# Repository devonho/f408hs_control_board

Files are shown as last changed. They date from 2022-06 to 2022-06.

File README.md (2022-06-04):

# Control board for Panasonic F-408HS 16" Stand Fan

## *** Warning  ***

This repository contains circuit designs for a printed circuit board that uses 240VAC as a power source, and can hence cause serious injury or death to anyone who implements the design. 

## Disclaimer

By using any of the designs here, you agree to waive the author of all liability for any personal or 3rd party injury or death, or damage to property sustained as a result of using the designs.

## License

These designs were made using a free version of [Autodesk Eagle](http://eagle.autodesk.com). Commercial use of designs is prohibited.

Furthermore: [License](./LICENSE)

## Overview

The design contained here contains both a [schematic](./eagle/F408HS_control.sch) that is inspired by the original board design, and a board [layout](./eagle/F408HS_control.brd) that has been revamped and optimized for 2-layer fabrication and debugging.

## Components and BOM

Most of the components used have been listed in the [Bill-Of-Materials](./eagle/BOM.txt) list. Some special ones that were hard to locate are connectors for the motor (CN1) and the AC input to the control board itself. These are:

* Japan Automatic Machine (JAM) SC25-10WL
* Japan Solderless Terminals (JST) ELR-03V

### Component Values

Values for transistors Q1 and Q2 were determined based on SMD markings, which may be erroneous.

Values for capacitors and zener diode were determined empirically using simulation in [LTSpice](https://www.analog.com/en/design-center/design-tools-and-calculators/ltspice-simulator.html). 

## LT SPICE Simulations

* [Power](./spice/power.asc)
* [Phase Sync](./spice/phase_sync.asc)

## Layout

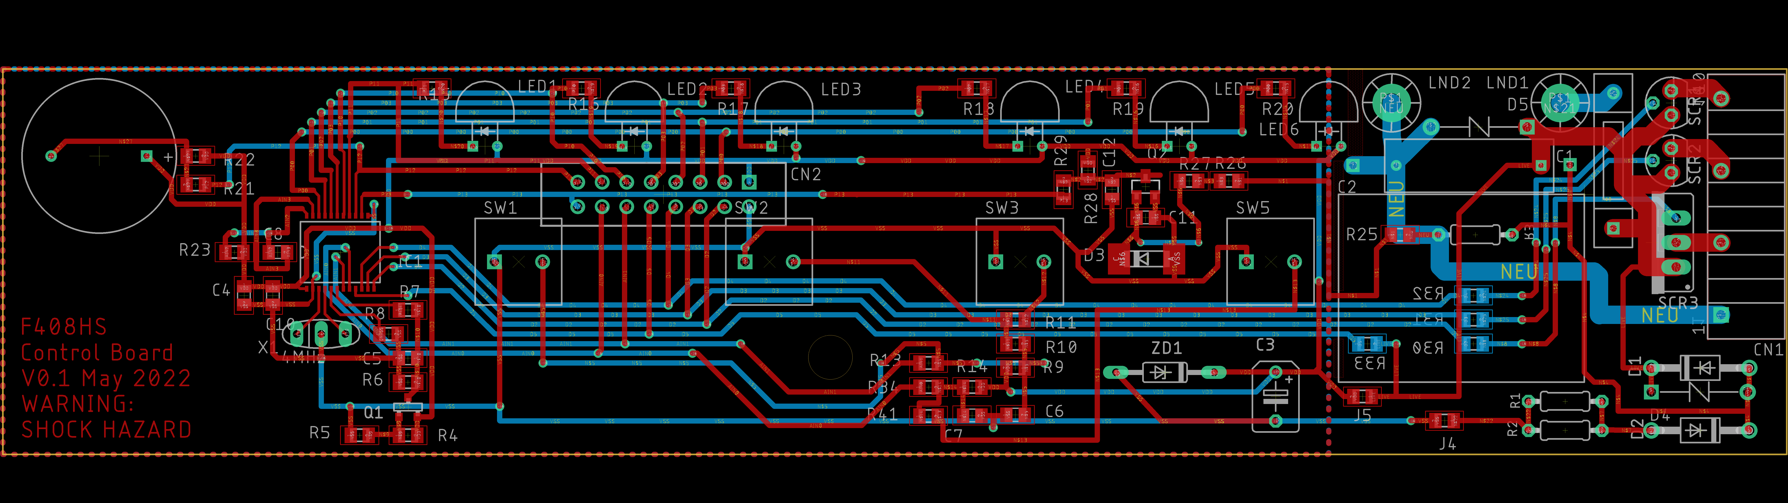
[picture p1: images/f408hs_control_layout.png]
Board layout


The [layout](./eagle/F408HS_control.brd) was designed with 2 layer boards in mind. Without the contraints of a single layer board, J1 - J3 are no longer needed to bridge over tracks.

The 240AC tracks have also been constrained to the right side of the board, making it slightly less risky while probing the board. The AC section can also be left unpopulated, using an externally sourced Vdd and Vss via CN2 for debugging the low voltage section. 

 ## Schematic

 Schematic

 ### AC Phase Sync

 The output of the AC phase sync circuit is connected to P13 of the MCU. Hence it is possible that the interrupt capability of that pin is used to synchronise the TRIAC trigger with the AC phase. Modulating the TRIAC duty cycle is probably needed for the 揺らぎ "Yuragi" fluctuation function, to lower the motor RPM.

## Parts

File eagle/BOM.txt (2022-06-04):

Partlist exported from C:/Users/Devon/OneDrive/projects/f408hs_control_board/eagle/F408HS_control.sch at 4/6/2022 4:26 PM

Part  Value         Device         Package        Description                                                    MF MPN         OC_FARNELL OC_NEWARK POPULARITY SPICEPREFIX
BZ1   BUZZER        BUZZER         BUZZER                                                                                                                                  
C1    0.1uF         ECQU2A104      ECQU2A104                                                                                                                               
C2    0.68uF        ECQUL2A648KL   ECQU2A684      Panasonic ECQUL Polyester Film Capacitor, 275V ac, ±10%, 680nF                                                           
C3    1000uF        CPOL-EUB45181B B45181B        POLARIZED CAPACITOR, European symbol                                                               2          C          
C4    10nF          C-EUC0805      C0805          CAPACITOR, European symbol                                                                         88         C          
C5    10nF          C-EUC0805      C0805          CAPACITOR, European symbol                                                                         88         C          
C6    10nF          C-EUC0805      C0805          CAPACITOR, European symbol                                                                         88         C          
C7    10nF          C-EUC0805      C0805          CAPACITOR, European symbol                                                                         88         C          
C8    10nF          C-EUC0805      C0805          CAPACITOR, European symbol                                                                         88         C          
C10   10nF          C-EUC0805      C0805          CAPACITOR, European symbol                                                                         88         C          
C11   1uF           C-EUC0805      C0805          CAPACITOR, European symbol                                                                         88         C          
C12   10nF          C-EUC0805      C0805          CAPACITOR, European symbol                                                                         88         C          
CN1   SC25-10WS     SC25-10WS      SC25-10WS                                                                                                                               
CN2   HEADER16      HEADER16       PAK100/2500-16                                                                                                                          
D1    SD103CWS-7-F  1N4004         DO41-10        DIODE                                                                                              82                    
D2    SD103CWS-7-F  1N4004         DO41-10        DIODE                                                                                              82                    
D3                  DIODE-SOD106-W SOD106-W       DIODE                                                                                              0                     
D4    V10241U       TVS            E14-S1         Panasonic "ZNR" Transient/Surge Absorbers"                                                                               
D5    V14511U       TVS            E14-S1         Panasonic "ZNR" Transient/Surge Absorbers"                                                                               
FUSE1 3.15A         FUSE           FUSE                                                                                                                                    
IC1   M34509G4FP    M34509G4FP     SSOP24                                                                                                                                  
J4    0R            R-EU_M0805     M0805          RESISTOR, European symbol                                                                          45         R          
J5    0R            R-EU_M0805     M0805          RESISTOR, European symbol                                                                          45         R          
LED1  LED_PTH_HORIZ LED_PTH_HORIZ  LED_HORIZ                                                                                                                               
LED2  LED_PTH_HORIZ LED_PTH_HORIZ  LED_HORIZ                                                                                                                               
LED3  LED_PTH_HORIZ LED_PTH_HORIZ  LED_HORIZ                                                                                                                               
LED4  LED_PTH_HORIZ LED_PTH_HORIZ  LED_HORIZ                                                                                                                               
LED5  LED_PTH_HORIZ LED_PTH_HORIZ  LED_HORIZ                                                                                                                               
LED6  LED_PTH_HORIZ LED_PTH_HORIZ  LED_HORIZ                                                                                                                               
LND1  LND           LND            LND                                                                                                                                     
LND2  LND           LND            LND                                                                                                                                     
Q1                  PNPSOT23       SOT-23         PNP TRANSISTOR                                                    DSS20200L-7 unknown    25R4554   0                     
Q2    MMBR536       MMBR536        SOT23                                                                                                                                   
R1    100R          R-EU_0204/7    0204/7         RESISTOR, European symbol                                                                          79         R          
R2    100R          R-EU_0204/7    0204/7         RESISTOR, European symbol                                                                          79         R          
R3    910K          R-EU_0204/7    0204/7         RESISTOR, European symbol                                                                          79         R          
R4    1K6           R-EU_M0805     M0805          RESISTOR, European symbol                                                                          45         R          
R5    7K5           R-EU_M0805     M0805          RESISTOR, European symbol                                                                          45         R          
R6    10K           R-EU_M0805     M0805          RESISTOR, European symbol                                                                          45         R          
R7    10K           R-EU_M0805     M0805          RESISTOR, European symbol                                                                          45         R          
R8    1K5           R-EU_M0805     M0805          RESISTOR, European symbol                                                                          45         R          
R9    8K2           R-EU_M0805     M0805          RESISTOR, European symbol                                                                          45         R          
R10   5K6           R-EU_M0805     M0805          RESISTOR, European symbol                                                                          45         R          
R11   7K5           R-EU_M0805     M0805          RESISTOR, European symbol                                                                          45         R          
R13   1K            R-EU_M0805     M0805          RESISTOR, European symbol                                                                          45         R          
R14   8K2           R-EU_M0805     M0805          RESISTOR, European symbol                                                                          45         R          
R15   2K            R-EU_M0805     M0805          RESISTOR, European symbol                                                                          45         R          
R16   2K            R-EU_M0805     M0805          RESISTOR, European symbol                                                                          45         R          
R17   2K            R-EU_M0805     M0805          RESISTOR, European symbol                                                                          45         R          
R18   2K            R-EU_M0805     M0805          RESISTOR, European symbol                                                                          45         R          
R19   2K            R-EU_M0805     M0805          RESISTOR, European symbol                                                                          45         R          
R20   2K            R-EU_M0805     M0805          RESISTOR, European symbol                                                                          45         R          
R21   1K            R-EU_M0805     M0805          RESISTOR, European symbol                                                                          45         R          
R22   1K            R-EU_M0805     M0805          RESISTOR, European symbol                                                                          45         R          
R23   10K           R-EU_M0805     M0805          RESISTOR, European symbol                                                                          45         R          
R25   130K          R-EU_R0805     R0805          RESISTOR, European symbol                                                                          86         R          
R26   130K          R-EU_R0805     R0805          RESISTOR, European symbol                                                                          86         R          
R27   130K          R-EU_R0805     R0805          RESISTOR, European symbol                                                                          86         R          
R28   18K           R-EU_M0805     M0805          RESISTOR, European symbol                                                                          45         R          
R29   1K            R-EU_M0805     M0805          RESISTOR, European symbol                                                                          45         R          
R30   750R          R-EU_M0805     M0805          RESISTOR, European symbol                                                                          45         R          
R31   750R          R-EU_M0805     M0805          RESISTOR, European symbol                                                                          45         R          
R32   750R          R-EU_M0805     M0805          RESISTOR, European symbol                                                                          45         R          
R33   750R          R-EU_M0805     M0805          RESISTOR, European symbol                                                                          45         R          
R34   1K            R-EU_M0805     M0805          RESISTOR, European symbol                                                                          45         R          
R41   5K6           R-EU_M0805     M0805          RESISTOR, European symbol                                                                          45         R          
SCR1  BCR1AM        BCR1AM         TO92                                                                                                                                    
SCR2  BCR1AM        BCR1AM         TO92                                                                                                                                    
SCR3  TMG3D60C      TIC225S        TO220DS        TRIAC                                                                                              0                     
SW1   EVQ11         EVQ11          EVQ11                                                                                                                                   
SW2   EVQ11         EVQ11          EVQ11                                                                                                                                   
SW3   EVQ11         EVQ11          EVQ11                                                                                                                                   
SW5   EVQ11         EVQ11          EVQ11                                                                                                                                   
X1    4MHz          CSTLS_G        CSTLS_G8       Ceramic resonator 2.00 to 10.00 MHz                                                                                      
ZD1   DDZ4V7ASF-7   1N821          DO35Z10        Reference DIODE                                                                                    1

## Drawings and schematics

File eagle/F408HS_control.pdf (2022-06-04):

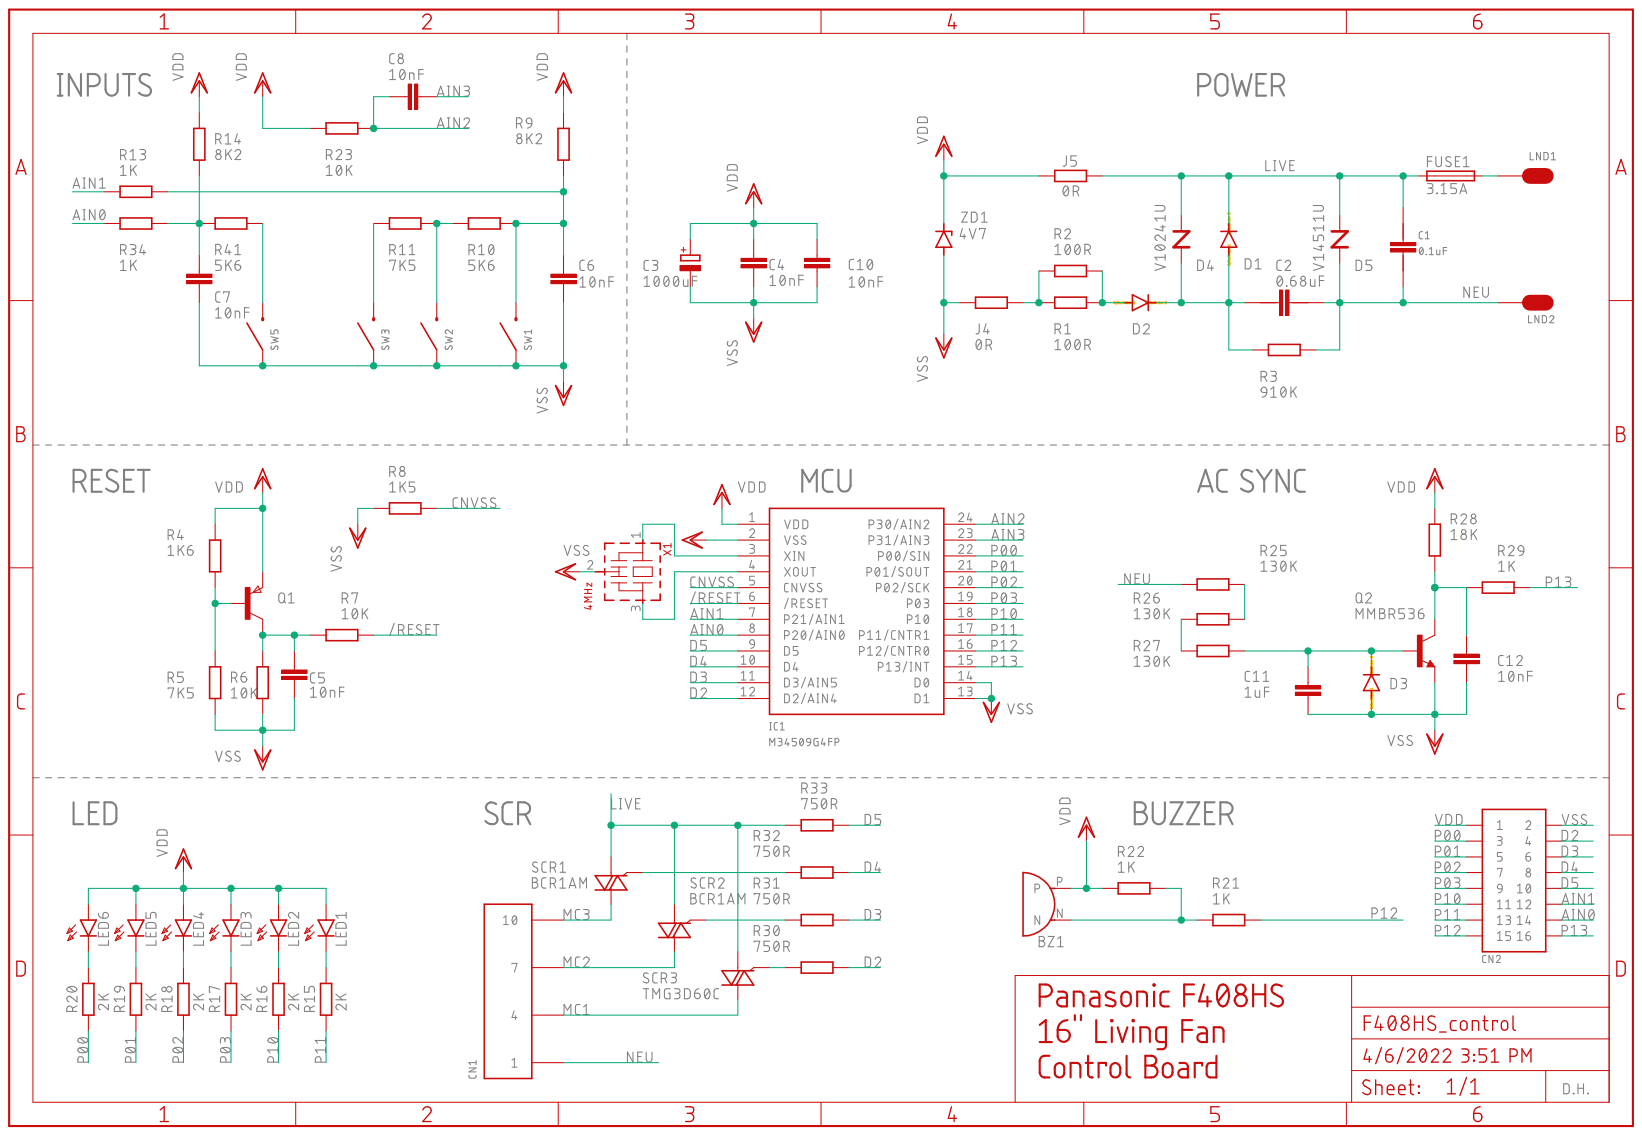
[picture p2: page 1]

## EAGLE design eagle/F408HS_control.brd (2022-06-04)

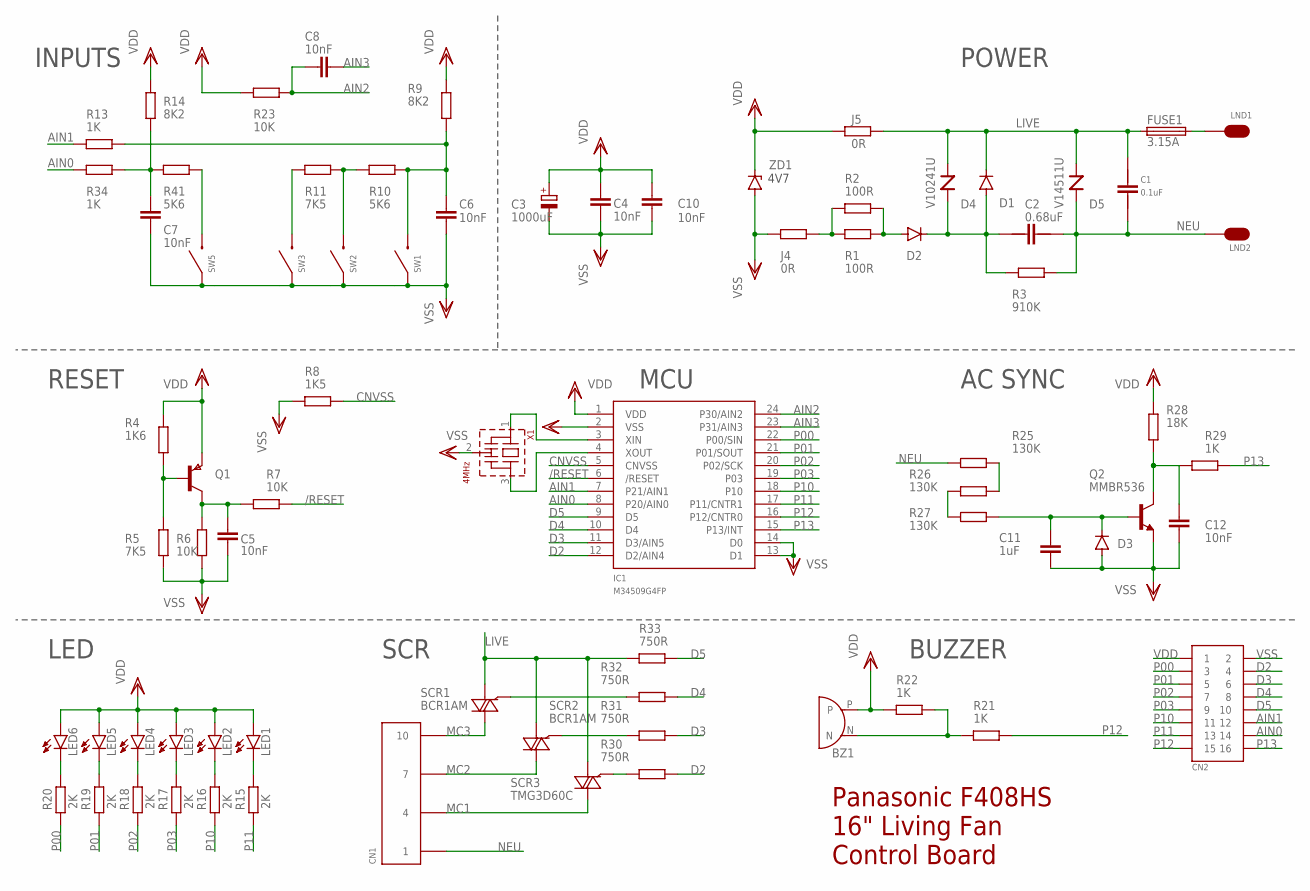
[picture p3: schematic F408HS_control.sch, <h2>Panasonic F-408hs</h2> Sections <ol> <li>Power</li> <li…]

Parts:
BZ1: BUZZER
C1: 0.1uF; ECQU2A104
C2: 0.68uF; ECQU2A684
C3: 1000uF; B45181B
C4, C5, C6, C7, C8, C10, C12: 10nF; C0805
C11: 1uF; C0805
CN1: SC25-10WS
CN2: HEADER16; PAK100/2500-16
D1, D2: SD103CWS-7-F; DO41-10
D3: DIODE-SOD106-W; SOD106-W
D4: V10241U; E14-S1
D5: V14511U; E14-S1
FUSE1: 3.15A; FUSE
IC1: M34509G4FP; SSOP24
J4, J5: 0R; M0805
LED1, LED2, LED3, LED4, LED5, LED6: LED_PTH_HORIZ; LED_HORIZ
LND1, LND2: LND
Q1: PNPSOT23; SOT-23
Q2: MMBR536; SOT23
R1, R2: 100R; 0204/7
R3: 910K; 0204/7
R4: 1K6; M0805
R5, R11: 7K5; M0805
R6, R7, R23: 10K; M0805
R8: 1K5; M0805
R9, R14: 8K2; M0805
R10, R41: 5K6; M0805
R13, R21, R22, R29, R34: 1K; M0805
R15, R16, R17, R18, R19, R20: 2K; M0805
R25, R26, R27: 130K; R0805
R28: 18K; M0805
R30, R31, R32, R33: 750R; M0805
SCR1, SCR2: BCR1AM; TO92
SCR3: TMG3D60C; TO220DS
SW1, SW2, SW3, SW5: EVQ11
X1: 4MHz; CSTLS_G8
ZD1: DDZ4V7ASF-7; DO35Z10

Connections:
/RESET: IC1.6 (/RESET), R7.1
AIN0: CN2.14, IC1.8 (P20/AIN0), R34.1
AIN1: CN2.12, IC1.7 (P21/AIN1), R13.1
AIN2: C8.1, IC1.24 (P30/AIN2), R23.1
AIN3: C8.2, IC1.23 (P31/AIN3)
CNVSS: IC1.5 (CNVSS), R8.1
D2: CN2.4, IC1.12 (D2/AIN4), R30.1
D3: CN2.6, IC1.11 (D3/AIN5), R31.1
D4: CN2.8, IC1.10 (D4), R32.1
D5: CN2.10, IC1.9 (D5), R33.1
LIVE: C1.P$1, D1.C, D4.P$1, D5.P$1, FUSE1.P$1 (1), J5.1, R33.2, SCR1.1 (A1), SCR2.1 (A1), SCR3.A1
MC1: CN1.P$4 (4), SCR3.A2
MC2: CN1.P$7 (7), SCR2.3 (A2)
MC3: CN1.P$10 (10), SCR1.3 (A2)
unnamed: R25.1, R26.2
unnamed: C12.2, Q2.3 (C), R28.2, R29.2
unnamed: R26.1, R27.2
unnamed: C2.P$1, D1.A, D2.C, D4.P$2, R3.1
unnamed: C6.2, R9.1, R10.2, R13.2, SW1.P$2
unnamed: C11.2, D3.C, Q2.1 (B), R27.1
unnamed: D2.A, R1.2, R2.2
unnamed: R30.2, SCR3.G
unnamed: Q1.3 (B), R4.1, R5.2
unnamed: C5.1, Q1.1 (C), R6.2, R7.2
unnamed: R10.1, R11.2, SW2.P$2
unnamed: R11.1, SW3.P$2
unnamed: R41.2, SW5.P$2
unnamed: C7.1, R14.1, R34.2, R41.1
unnamed: LED6.N (K), R20.2
unnamed: LED5.N (K), R19.2
unnamed: LED4.N (K), R18.2
unnamed: LED3.N (K), R17.2
unnamed: LED2.N (K), R16.2
unnamed: LED1.N (K), R15.2
unnamed: FUSE1.P$2 (2), LND1.P$1
unnamed: J4.1, R1.1, R2.1
unnamed: R32.2, SCR1.2 (G)
unnamed: R31.2, SCR2.2 (G)
unnamed: BZ1.N, R21.2, R22.1
unnamed: IC1.3 (XIN), X1.1
unnamed: IC1.4 (XOUT), X1.3
NEU: C1.P$2, C2.P$2, CN1.P$1 (1), D5.P$2, LND2.P$1, R3.2, R25.2
P00: CN2.3, IC1.22 (P00/SIN), R20.1
P01: CN2.5, IC1.21 (P01/SOUT), R19.1
P02: CN2.7, IC1.20 (P02/SCK), R18.1
P03: CN2.9, IC1.19 (P03), R17.1
P10: CN2.11, IC1.18 (P10), R16.1
P11: CN2.13, IC1.17 (P11/CNTR1), R15.1
P12: CN2.15, IC1.16 (P12/CNTR0), R21.1
P13: CN2.16, IC1.15 (P13/INT), R29.1
VDD: BZ1.P, C3.+, C4.1, C10.1, CN2.1, IC1.1 (VDD), J5.2, LED1.P (A), LED2.P (A), LED3.P (A), LED4.P (A), LED5.P (A), LED6.P (A), Q1.2 (E), R4.2, R9.2, R14.2, R22.2, R23.2, R28.1, ZD1.C
VSS: C3.-, C4.2, C5.2, C6.1, C7.2, C10.2, C11.1, C12.1, CN2.2, D3.A, IC1.2 (VSS), IC1.13 (D1), IC1.14 (D0), J4.2, Q2.2 (E), R5.1, R6.1, R8.2, SW1.P$1, SW2.P$1, SW3.P$1, SW5.P$1, X1.2 (VSS), ZD1.A

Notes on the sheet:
Panasonic F408HS 16" Living Fan Control Board
INPUTS
POWER
LED
MCU
RESET
AC SYNC
BUZZER
SCR
4V7

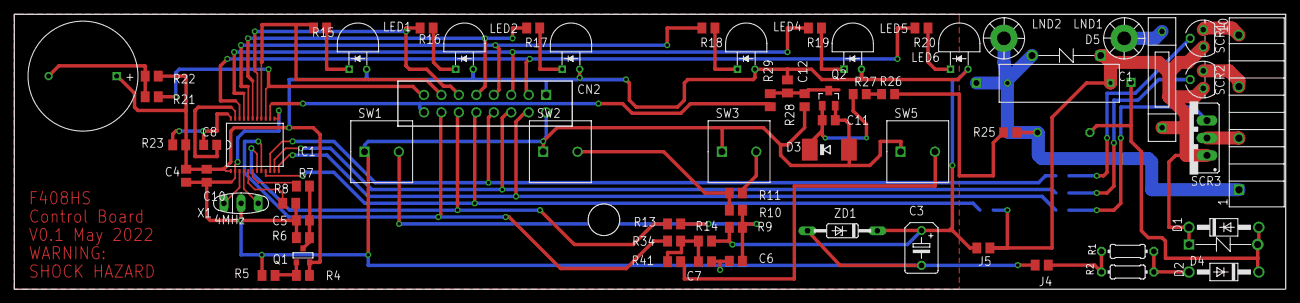
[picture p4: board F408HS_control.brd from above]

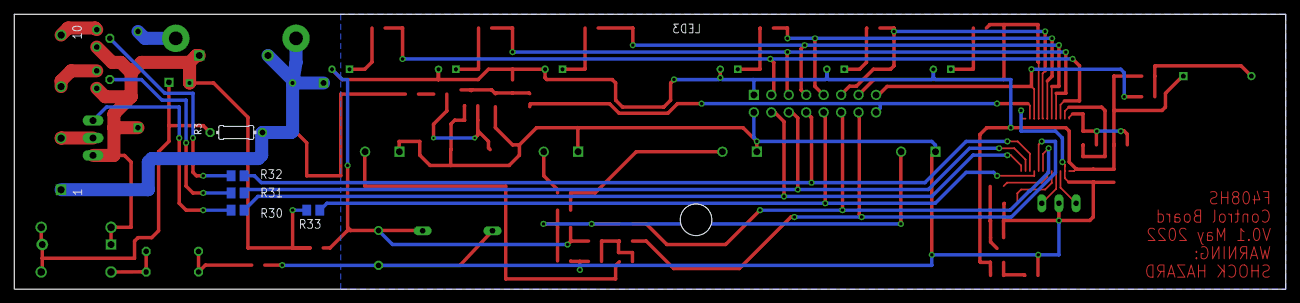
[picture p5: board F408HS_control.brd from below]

Board: 2 copper layers, 185.0 x 40.0 mm, 75 parts (5 on the bottom side), 52 nets.

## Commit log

2022-06-04 Initial checkin
    [F408HS_control.brd, F408HS_control.sch]
2022-06-04 added board image
